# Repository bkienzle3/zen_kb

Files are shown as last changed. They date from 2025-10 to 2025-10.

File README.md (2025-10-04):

# zen_kb

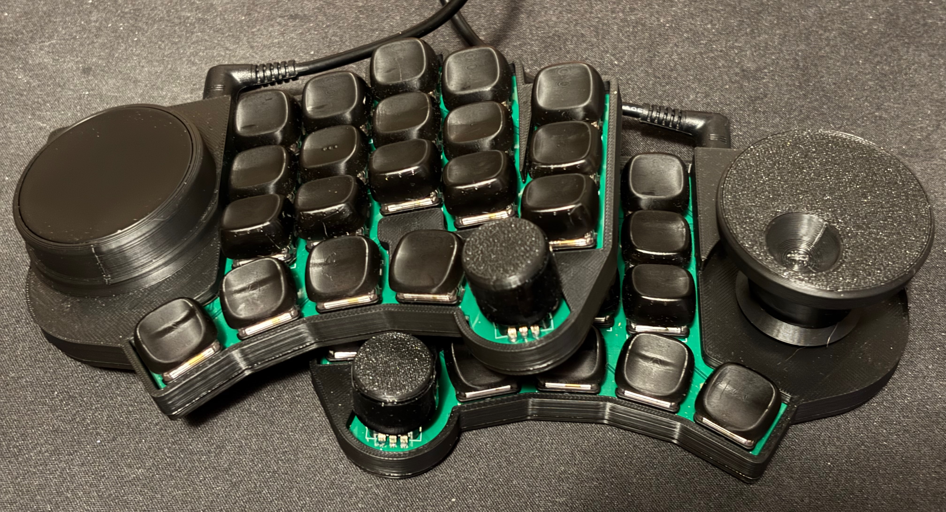
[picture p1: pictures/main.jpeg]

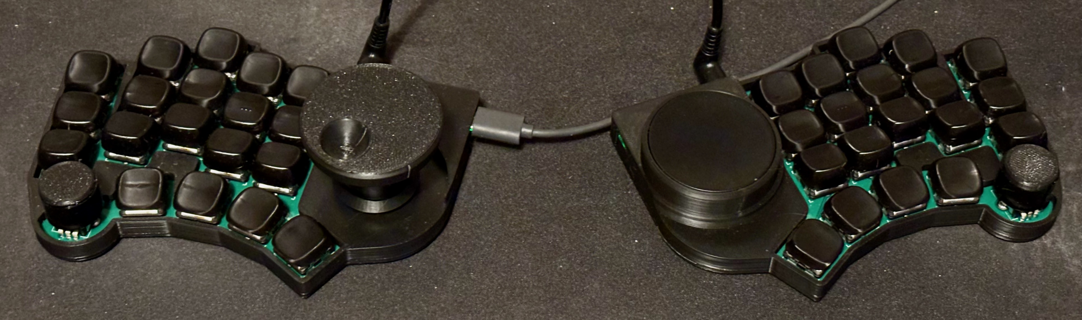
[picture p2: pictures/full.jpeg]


"Maximalist" ergo mech split keyboard. 38-keys, 3 rotary encoders, 1 trackpad. My last keyboard was mu (無), meaning nothing. Since this adds a lot of extra bells and whistles, I've named it zen (全), meaning all. This keyboard is meant to be much more "finished" than mu. With that said, this is still an eternal work in progress. The hardware is finished, at least. The config is a never ending journey.

## Firmware
Firmware is located in qmk_firmware. Keymaps are based on Miryoku (manna-harbour/miryoku), with my own customizations, of course.

## Bill of materials

Kailh Choc V1 key switches x 38
<br>KB2040 x 2 (MCU - runs on 3.3v, important for trackpad)
<br>1N4148 MiniMELF diode x 38
<br>TRRS-PJ-320A x 2 (TRRS jacks)
<br>Alps EC12E2440301 x 2 (Mini encoders)
<br>Alps EC12E24404A8 x 1 (Jog wheel encoder)
<br>Cirque TM040040-2024-303 x 1 (trackpad)
<br>Molex 505110-1297 x 1
<br>.50 mm pitch type B FFC x 1
<br>M2*6mm screws, hex socket head x 12
<br>M2 heat set inserts x 12

## Other
I recommend putting some sort of grip tape around the knobs. I'm using self-fusing silicone tape, but anything should work.

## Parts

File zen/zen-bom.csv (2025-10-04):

Id | Designator | Footprint | Quantity | Designation | Supplier and ref
1 | ,,,,,,,,,, |  | 11
2 | SW22,SW23,SW18,SW26,SW38,SW33,SW11,SW19,SW30,SW37,SW17,SW5,SW24,SW2,SW7,SW6,SW32,SW13,SW27,SW4,SW12,SW16,SW34,SW1,SW3,SW14,SW29,SW25,SW31,SW28,SW21,SW9,SW36,SW35,SW20,SW15,SW10,SW8 | SW_PG1350 | 38 | SW_Push
3 | U1,U2 | kb2040 | 2 | kb2040
4 | TRX2,TRX1 | TRRS-PJ-320A | 2 | TRRS
5 | ENC2,JOG1,ENC1 | EC12E2440301 | 3 | RotaryEncoder
6 | REF1,REF1 | Cirque Curved 40mm Trackpad | 2 | Cirque Curved Trackpad
7 | TKP1 | 5051101297 | 1 | Trackpad
8 | D33,D15,D14,D6,D38,D2,D31,D9,D22,D13,D26,D17,D24,D12,D36,D1,D16,D11,D28,D29,D7,D35,D8,D10,D20,D37,D23,D21,D32,D18,D3,D19,D25,D5,D27,D30,D4,D34 | D_MiniMELF | 38 | D

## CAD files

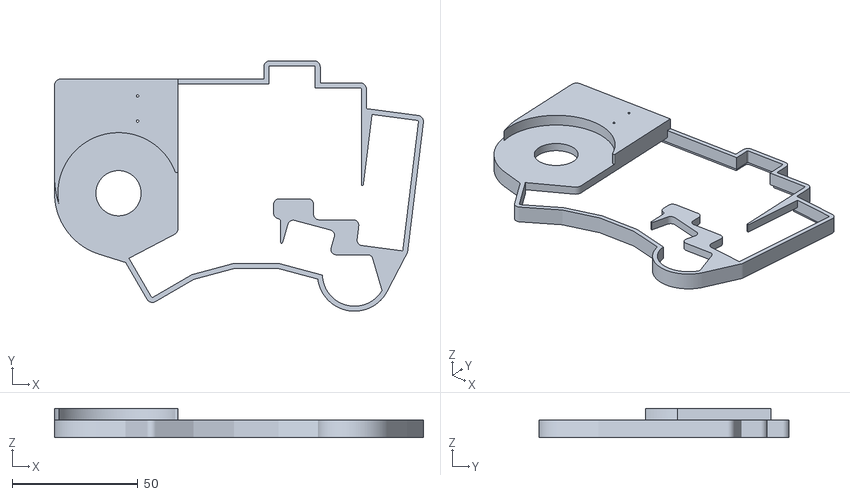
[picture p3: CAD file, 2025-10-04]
3d-printed-parts/case/topleft-needsmirrored.stl
147.0 x 99.7 x 11.6

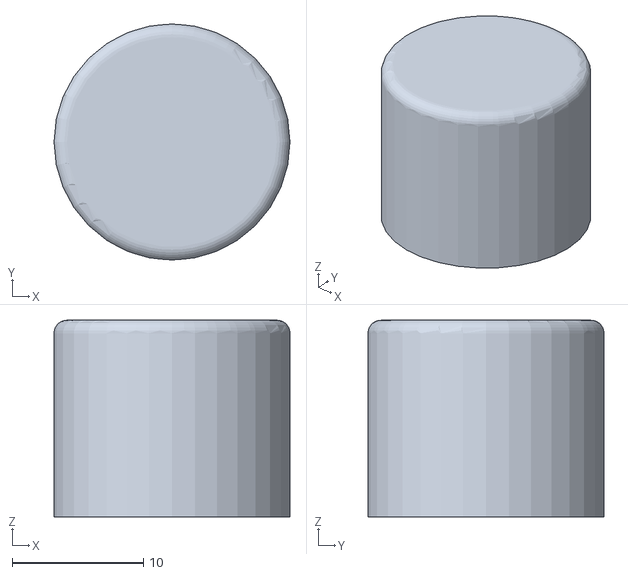
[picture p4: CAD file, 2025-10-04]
3d-printed-parts/wheels/smallknobs.stl
18.0 x 18.0 x 15.0

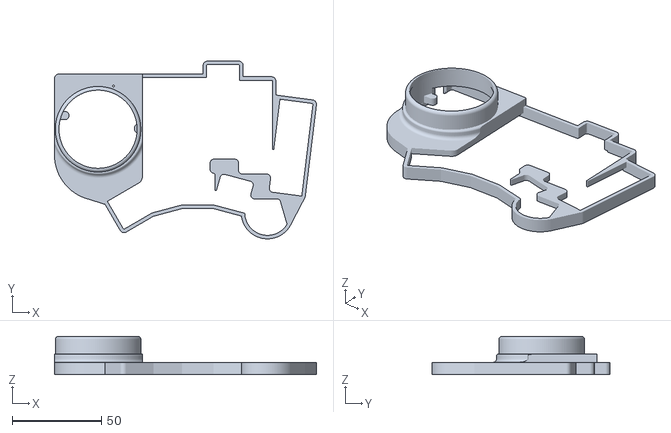
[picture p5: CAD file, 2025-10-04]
3d-printed-parts/case/topright.stl
147.0 x 99.7 x 21.6

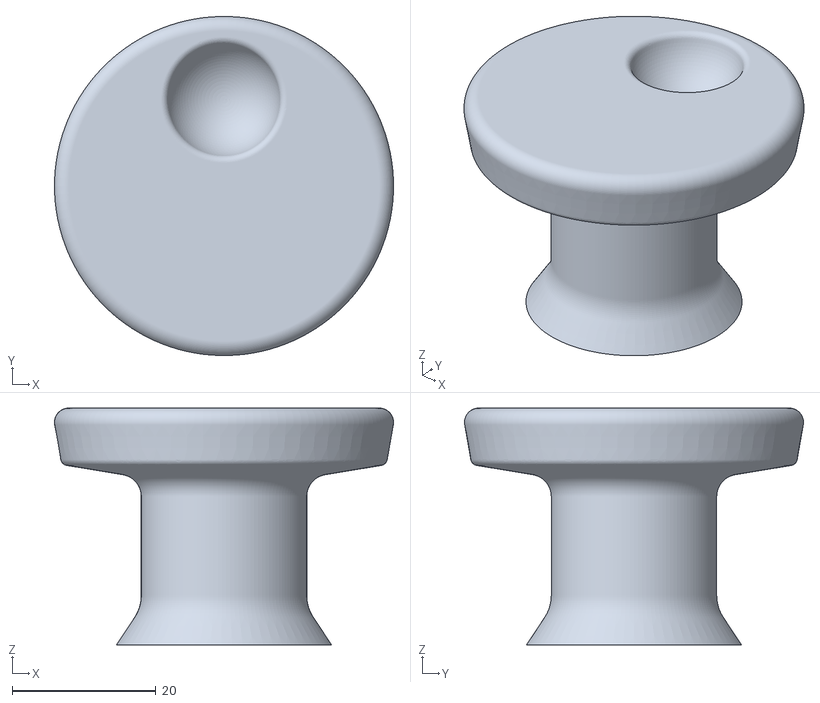
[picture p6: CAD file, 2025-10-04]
3d-printed-parts/wheels/jogwheel.stl
47.2 x 47.2 x 33.0

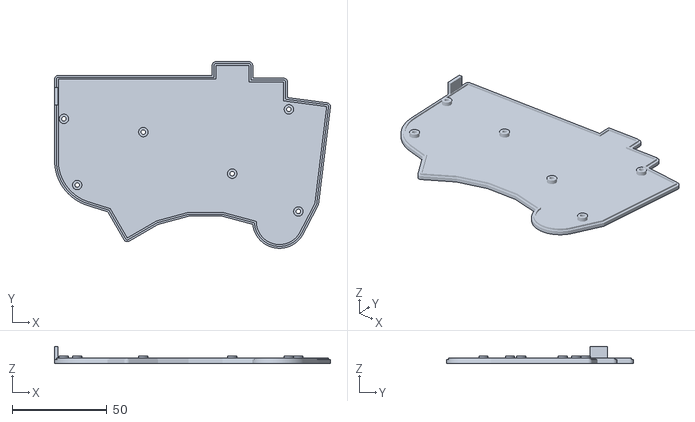
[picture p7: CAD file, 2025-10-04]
3d-printed-parts/case/bottom.stl
146.0 x 98.7 x 9.00

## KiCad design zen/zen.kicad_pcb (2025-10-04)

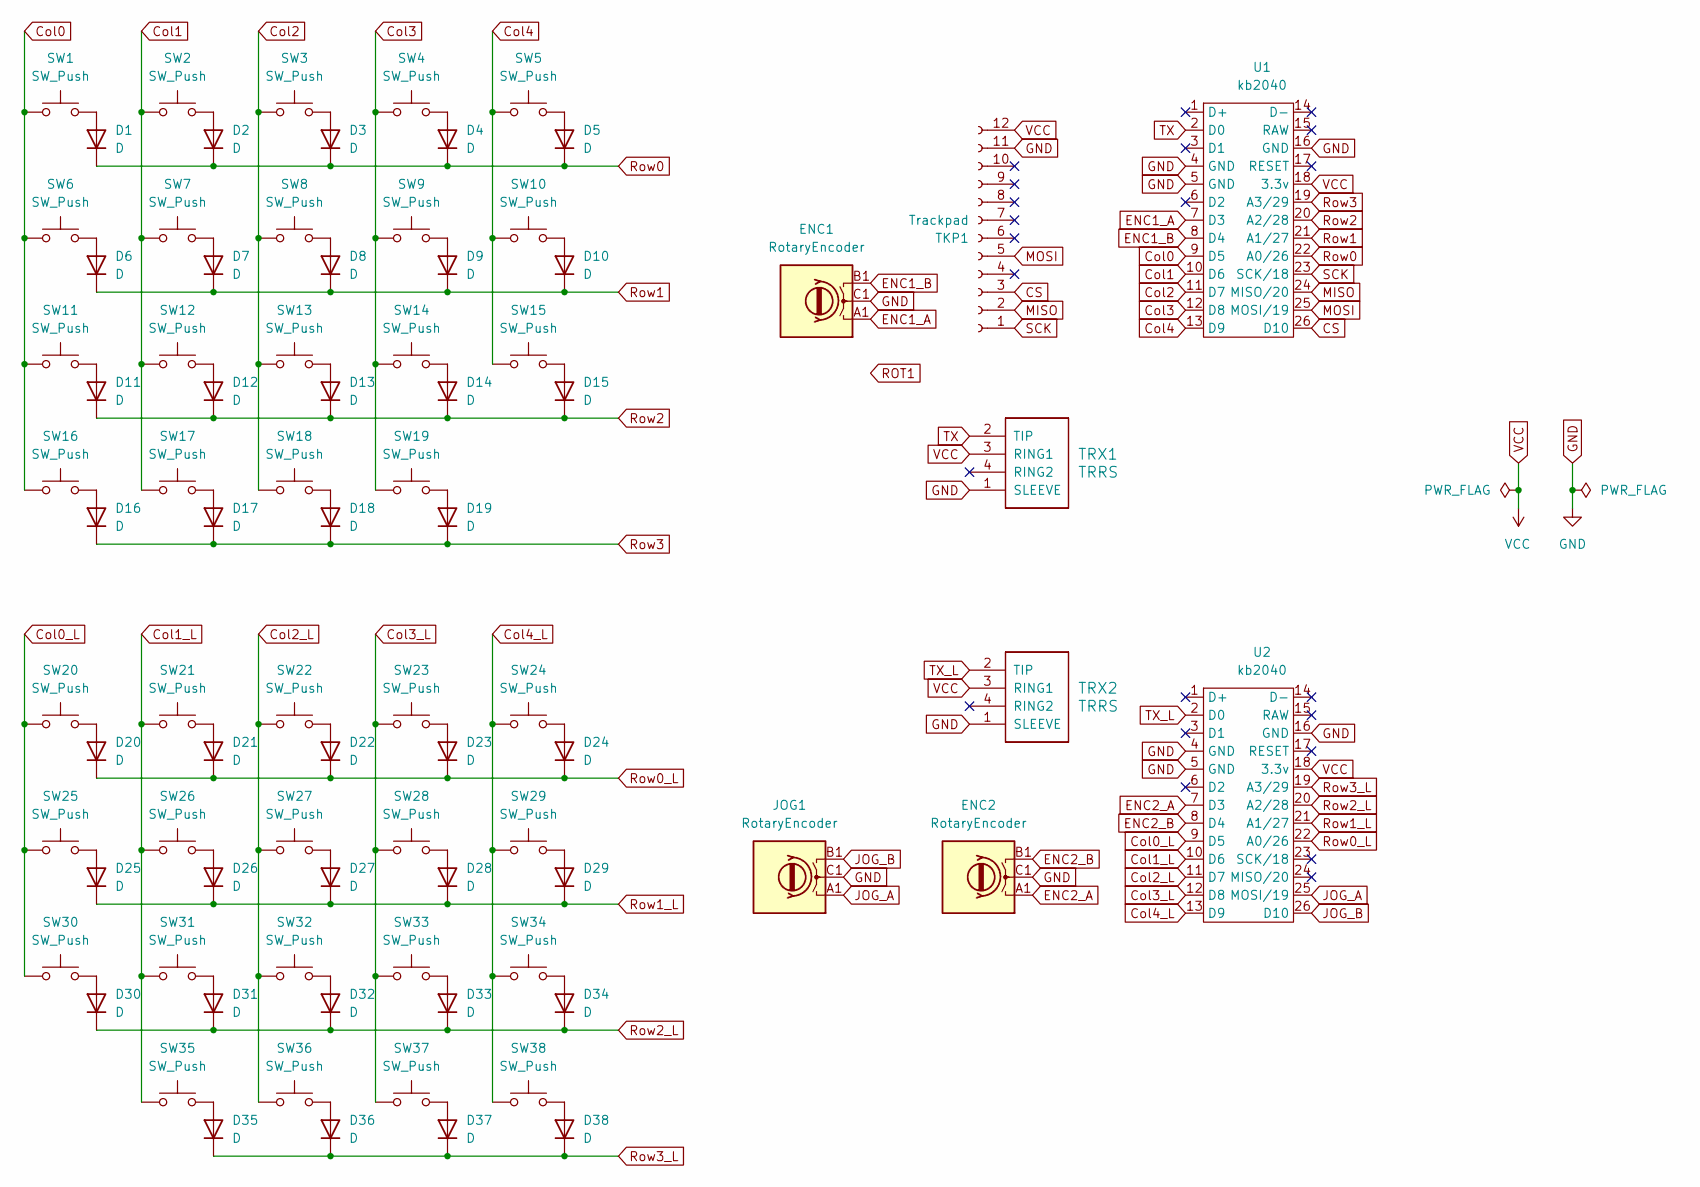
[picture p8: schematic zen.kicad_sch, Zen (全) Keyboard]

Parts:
D1, D2, D3, D4, D5, D6, D7, D8, D9, D10, D11, D12, D13, D14, D15, D16, D17, D18, D19, D20, D21, D22, D23, D24, D25, D26, D27, D28, D29, D30, D31, D32, D33, D34, D35, D36, D37, D38: D; D_MiniMELF
ENC1, ENC2: RotaryEncoder; EC12E2440301
JOG1: RotaryEncoder; EC12E2440301
SW1, SW2, SW3, SW4, SW5, SW6, SW7, SW8, SW9, SW10, SW11, SW12, SW13, SW14, SW15, SW16, SW17, SW18, SW19, SW20, SW21, SW22, SW23, SW24, SW25, SW26, SW27, SW28, SW29, SW30, SW31, SW32, SW33, SW34, SW35, SW36, SW37, SW38: SW_Push; SW_PG1350
TKP1: Trackpad; 5051101297
TRX1, TRX2: TRRS; TRRS-PJ-320A
U1, U2: kb2040

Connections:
CS: TKP1.3, U1.26 (D10)
Col0: SW1.1, SW6.1, SW11.1, SW16.1, U1.9 (D5)
Col0_L: SW20.1, SW25.1, SW30.1, U2.9 (D5)
Col1: SW2.1, SW7.1, SW12.1, SW17.1, U1.10 (D6)
Col1_L: SW21.1, SW26.1, SW31.1, SW35.1, U2.10 (D6)
Col2: SW3.1, SW8.1, SW13.1, SW18.1, U1.11 (D7)
Col2_L: SW22.1, SW27.1, SW32.1, SW36.1, U2.11 (D7)
Col3: SW4.1, SW9.1, SW14.1, SW19.1, U1.12 (D8)
Col3_L: SW23.1, SW28.1, SW33.1, SW37.1, U2.12 (D8)
Col4: SW5.1, SW10.1, SW15.1, U1.13 (D9)
Col4_L: SW24.1, SW29.1, SW34.1, SW38.1, U2.13 (D9)
ENC1_A: ENC1.A1, U1.7 (D3)
ENC1_B: ENC1.B1, U1.8 (D4)
ENC2_A: ENC2.A1, U2.7 (D3)
ENC2_B: ENC2.B1, U2.8 (D4)
GND: ENC1.C1, ENC2.C1, JOG1.C1, TKP1.11, TRX1.1 (SLEEVE), TRX2.1 (SLEEVE), U1.4 (GND), U1.5 (GND), U1.16 (GND), U2.4 (GND), U2.5 (GND), U2.16 (GND)
JOG_A: JOG1.A1, U2.25 (MOSI/19)
JOG_B: JOG1.B1, U2.26 (D10)
MISO: TKP1.2, U1.24 (MISO/20)
MOSI: TKP1.5, U1.25 (MOSI/19)
unnamed: D1.2 (A), SW1.2
unnamed: D2.2 (A), SW2.2
unnamed: D3.2 (A), SW3.2
unnamed: D4.2 (A), SW4.2
unnamed: D5.2 (A), SW5.2
unnamed: D6.2 (A), SW6.2
unnamed: D7.2 (A), SW7.2
unnamed: D8.2 (A), SW8.2
unnamed: D9.2 (A), SW9.2
unnamed: D10.2 (A), SW10.2
unnamed: D11.2 (A), SW11.2
unnamed: D12.2 (A), SW12.2
unnamed: D13.2 (A), SW13.2
unnamed: D14.2 (A), SW14.2
unnamed: D15.2 (A), SW15.2
unnamed: D16.2 (A), SW16.2
unnamed: D17.2 (A), SW17.2
unnamed: D18.2 (A), SW18.2
unnamed: D19.2 (A), SW19.2
unnamed: D20.2 (A), SW20.2
unnamed: D21.2 (A), SW21.2
unnamed: D22.2 (A), SW22.2
unnamed: D23.2 (A), SW23.2
unnamed: D24.2 (A), SW24.2
unnamed: D25.2 (A), SW25.2
unnamed: D26.2 (A), SW26.2
unnamed: D27.2 (A), SW27.2
unnamed: D28.2 (A), SW28.2
unnamed: D29.2 (A), SW29.2
unnamed: D30.2 (A), SW30.2
unnamed: D31.2 (A), SW31.2
unnamed: D32.2 (A), SW32.2
unnamed: D33.2 (A), SW33.2
unnamed: D34.2 (A), SW34.2
unnamed: D35.2 (A), SW35.2
unnamed: D36.2 (A), SW36.2
unnamed: D37.2 (A), SW37.2
unnamed: D38.2 (A), SW38.2
Row0: D1.1 (K), D2.1 (K), D3.1 (K), D4.1 (K), D5.1 (K), U1.22 (A0/26)
Row0_L: D20.1 (K), D21.1 (K), D22.1 (K), D23.1 (K), D24.1 (K), U2.22 (A0/26)
Row1: D6.1 (K), D7.1 (K), D8.1 (K), D9.1 (K), D10.1 (K), U1.21 (A1/27)
Row1_L: D25.1 (K), D26.1 (K), D27.1 (K), D28.1 (K), D29.1 (K), U2.21 (A1/27)
Row2: D11.1 (K), D12.1 (K), D13.1 (K), D14.1 (K), D15.1 (K), U1.20 (A2/28)
Row2_L: D30.1 (K), D31.1 (K), D32.1 (K), D33.1 (K), D34.1 (K), U2.20 (A2/28)
Row3: D16.1 (K), D17.1 (K), D18.1 (K), D19.1 (K), U1.19 (A3/29)
Row3_L: D35.1 (K), D36.1 (K), D37.1 (K), D38.1 (K), U2.19 (A3/29)
SCK: TKP1.1, U1.23 (SCK/18)
TX: TRX1.2 (TIP), U1.2 (D0)
TX_L: TRX2.2 (TIP), U2.2 (D0)
VCC: TKP1.12, TRX1.3 (RING1), TRX2.3 (RING1), U1.18 (3.3v), U2.18 (3.3v)

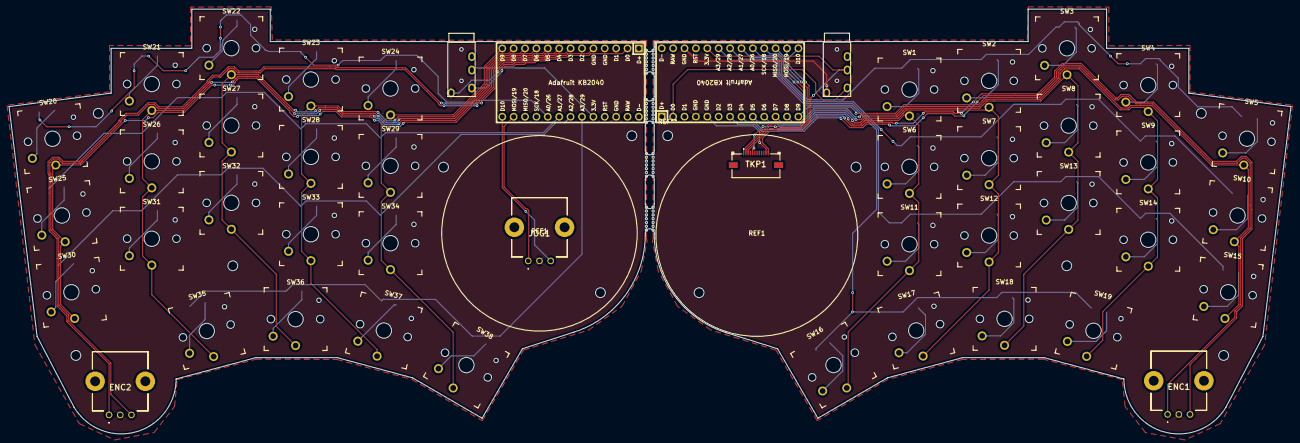
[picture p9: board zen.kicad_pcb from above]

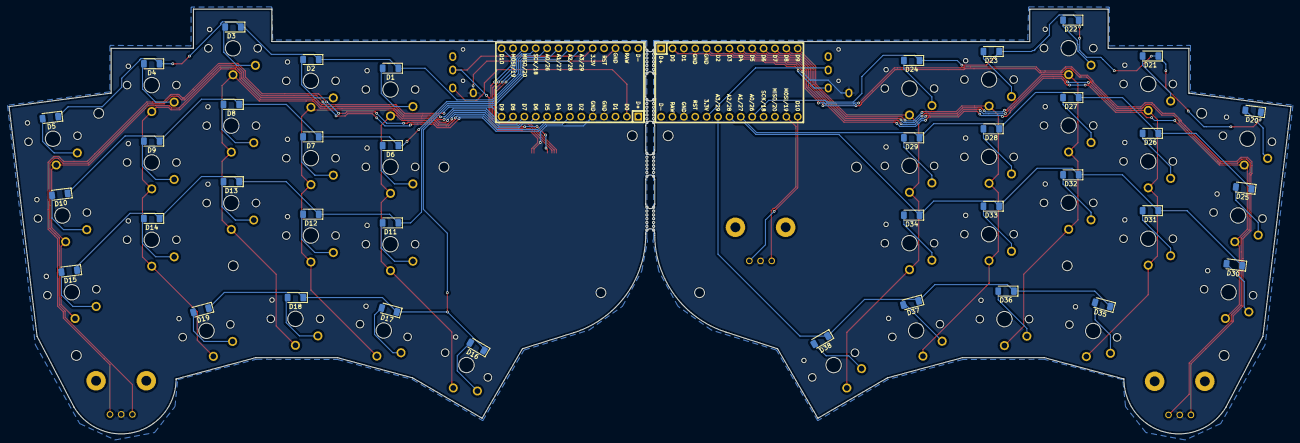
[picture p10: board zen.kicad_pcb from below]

Board: 2 copper layers, 285.9 x 94.7 mm, 86 parts (38 on the bottom side), 70 nets.

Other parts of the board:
REF1, REF1#2: Cirque Curved Trackpad; Cirque Curved 40mm Trackpad

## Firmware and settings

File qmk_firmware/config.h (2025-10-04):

// Copyright 2025 bkienzle3 (@bkienzle3)
// SPDX-License-Identifier: GPL-2.0-or-later

#pragma once

/*
 * Feature disable options
 *  These options are also useful to firmware size reduction.
 */

/* disable debug print */
//#define NO_DEBUG

#define ENCODER_A_PINS { GP3, GP19 }
#define ENCODER_B_PINS { GP4, GP10 }
#define ENCODER_RESOLUTIONS { 4, 4 }
#define ENCODER_A_PINS_RIGHT { GP3 }
#define ENCODER_B_PINS_RIGHT { GP4 }
#define ENCODER_RESOLUTIONS_RIGHT { 4 }



#define SPLIT_POINTING_ENABLE
#define POINTING_DEVICE_RIGHT
#define CIRQUE_PINNACLE_TAP_ENABLE
#define CIRQUE_PINNACLE_SECONDARY_TAP_ENABLE
#define POINTING_DEVICE_ROTATION_90
#define CIRQUE_PINNACLE_ATTENUATION EXTREG__TRACK_ADCCONFIG__ADC_ATTENUATE_2X
#define CIRQUE_PINNACLE_CURVED_OVERLAY

//#define SPI_DRIVER SPID0
#define SPI_SCK_PIN GP18
#define SPI_MOSI_PIN GP19
#define SPI_MISO_PIN GP20
#define POINTING_DEVICE_CS_PIN GP10
#undef CIRQUE_PINNACLE_DIAMETER_MM
#define CIRQUE_PINNACLE_DIAMETER_MM 40

//#define SPI_MOSI_PIN GP19
//#define SPI_MOSI_PIN GP20
/* disable print */
//#define NO_PRINT

/* disable action features */
//#define NO_ACTION_LAYER
//#define NO_ACTION_TAPPING
#define NO_ACTION_ONESHOT

// handedness
#define EE_HANDS

// mouse settings
#define MOUSEKEY_INTERVAL 16
#define MOUSEKEY_TIME_TO_MAX 60
#define MOUSEKEY_MAX_SPEED 15
#define MOUSEKEY_MOVE_DELTA 3
#define MOUSEKEY_DELAY 10
#define MOUSEKEY_WHEEL_DELTA 1
#define MOUSEKEY_WHEEL_MAX_SPEED 1

// homerow mods
#define TAPPING_TERM 200
#define QUICK_TAP_TERM 90
#define TAPPING_TERM_PER_KEY

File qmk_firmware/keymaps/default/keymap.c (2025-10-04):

#include QMK_KEYBOARD_H


/* zen keymap
 * home row mods
 */


// layers
enum layers {
    BASE = 0,
    NAV,
    SYM,
    MOUSE,
    NUMS,
    FNS,
    MEDIA,
    CFG,
    BUTTON,
    GFPS,
    GGEN,
    GEXT,
};


//// home row mods for qwerty
#define KC_HRA LGUI_T(KC_A)
#define KC_HRS LALT_T(KC_S)
#define KC_HRD LSFT_T(KC_D)
#define KC_HRF LCTL_T(KC_F)
#define KC_HRJ LCTL_T(KC_J)
#define KC_HRK LSFT_T(KC_K)
#define KC_HRL LALT_T(KC_L)
#define KC_HRQU LGUI_T(KC_QUOT)

// button layer tap
#define KC_BLTZ LT(BUTTON, KC_Z)
#define KC_BLTSH LT(BUTTON, KC_SLSH)

//// thumb buttons
#define KC_THT LT(NAV,KC_TAB)
#define KC_THS LT(MOUSE,KC_SPC)
#define KC_THE LT(SYM,KC_ENT)
#define KC_THB LT(NUMS,KC_BSPC)
#define KC_THESC LT(MEDIA,KC_ESC)
#define KC_THDEL LT(FNS,KC_DEL)

//// copy/paste
#define KC_MCOPY LCTL(KC_C)
#define KC_MPSTE LCTL(KC_V)
#define KC_MCUT LCTL(KC_X)
#define KC_MUNDO LCTL(KC_Z)
#define KC_MREDO LCTL(KC_Y)

//// misc
#define KC_PRVL LALT(KC_LEFT)
#define KC_MSBCK MS_BTN4
#define KC_MSFWD MS_BTN5
#define BR_NTAB LCTL(KC_PGDN)
#define BR_PTAB LCTL(KC_PGUP)

/// gaming
#define KC_GEXT MO(GEXT)
#define KC_GFPS TG(GFPS)
#define KC_GGEN TG(GGEN)
#define KC_BASE TG(BASE)
#define KC_ENTGX LT(GEXT,KC_ENT)


const uint16_t PROGMEM keymaps[][MATRIX_ROWS][MATRIX_COLS] = {



   // base (qwerty) layer
   [BASE] = LAYOUT_split_3x5_4(
   //,--------------------------------------------.                    ,--------------------------------------------.
          KC_Q,    KC_W,    KC_E,    KC_R,    KC_T,                         KC_Y,    KC_U,    KC_I,    KC_O,    KC_P,
   //|--------+--------+--------+--------+--------|                    |--------+--------+--------+--------+--------|
        KC_HRA,  KC_HRS,  KC_HRD,  KC_HRF,    KC_G,                         KC_H,  KC_HRJ,  KC_HRK,  KC_HRL, KC_HRQU,
   //|--------+--------+--------+--------+--------|                    |--------+--------+--------+--------+--------|
       KC_BLTZ,    KC_X,    KC_C,    KC_V,    KC_B,                         KC_N,    KC_M, KC_COMM,  KC_DOT,KC_BLTSH,
   //|--------+--------+--------+--------+--------+--------|  |--------+--------+--------+--------+--------+--------|
                           KC_NO,KC_THESC,  KC_THT,  KC_THS,     KC_THE,  KC_THB, KC_THDEL,  KC_NO
                     //`-----------------------------------'  `-----------------------------------'
   ),

   // nav layer
   [NAV] = LAYOUT_split_3x5_4(
   //,--------------------------------------------.                    ,--------------------------------------------.
        KC_F13,  KC_F14,  KC_F15,  KC_F16,  KC_F17,                     KC_MPSTE,KC_MCOPY, KC_MCUT,KC_MUNDO,KC_MREDO,
   //|--------+--------+--------+--------+--------|                    |--------+--------+--------+--------+--------|
       KC_LGUI, KC_LALT, KC_LSFT, KC_LCTL, KC_PRVL,                      KC_LEFT, KC_DOWN,   KC_UP, KC_RGHT, KC_CAPS,
   //|--------+--------+--------+--------+--------|                    |--------+--------+--------+--------+--------|
        KC_APP,  KC_F18,  KC_F19,  KC_F21,  KC_F22,                      KC_HOME, KC_PGDN, KC_PGUP,  KC_END,  KC_INS,
   //|--------+--------+--------+--------+--------+--------|  |--------+--------+--------+--------+--------+--------|
                           KC_NO, KC_TRNS, KC_TRNS, KC_TRNS,     KC_ENT, KC_BSPC,  KC_DEL,   KC_NO
                     //`-----------------------------------'  `-----------------------------------'
   ),

   // mouse/fancy/orphans
   [MOUSE] = LAYOUT_split_3x5_4(
   //,--------------------------------------------.                    ,--------------------------------------------.
         KC_NO,   KC_NO,   KC_NO,   KC_NO,   KC_NO,                     KC_MSBCK,   KC_NO,   KC_NO,KC_MSFWD,   KC_NO,
   //|--------+--------+--------+--------+--------|                    |--------+--------+--------+--------+--------|
       KC_LGUI, KC_LALT, KC_LSFT, KC_LCTL,   KC_NO,                      MS_LEFT, MS_DOWN,   MS_UP, MS_RGHT,   KC_NO,
   //|--------+--------+--------+--------+--------|                    |--------+--------+--------+--------+--------|
         KC_NO,   KC_NO,   KC_NO,   KC_NO,   KC_NO,                      MS_WHLL, MS_WHLD, MS_WHLU, MS_WHLR,   KC_NO,
   //|--------+--------+--------+--------+--------+--------|  |--------+--------+--------+--------+--------+--------|
                           KC_NO, KC_TRNS, KC_TRNS, KC_TRNS,    MS_BTN1, MS_BTN2, MS_BTN3,   KC_NO
                     //`-----------------------------------'  `-----------------------------------'
   ),

   // convienience buttons
   [BUTTON] = LAYOUT_split_3x5_4(
   //,--------------------------------------------.                    ,--------------------------------------------.
         KC_NO,  KC_F10,  KC_F11,  KC_F12,  KC_F24,                        KC_NO,   KC_NO,   KC_NO, KC_WAKE,  KC_PWR,
   //|--------+--------+--------+--------+--------|                    |--------+--------+--------+--------+--------|
         KC_NO,   KC_NO,   KC_NO,   KC_F5,KC_MUNDO,                        KC_NO,   KC_NO,   KC_NO,   KC_NO,   KC_NO,
   //|--------+--------+--------+--------+--------|                    |--------+--------+--------+--------+--------|
         KC_NO, KC_MCUT,KC_MCOPY,KC_MPSTE,KC_MREDO,                      MS_WHLL, MS_WHLD, MS_WHLU, MS_WHLR,   KC_NO,
   //|--------+--------+--------+--------+--------+--------|  |--------+--------+--------+--------+--------+--------|
                           KC_NO,   KC_NO,   KC_NO,   KC_NO,      KC_NO,   KC_NO,   KC_NO,   KC_NO
                     //`-----------------------------------'  `-----------------------------------'
   ),

   // numbers
   [NUMS] = LAYOUT_split_3x5_4(
   //,--------------------------------------------.                    ,--------------------------------------------.
       KC_LBRC,    KC_7,    KC_8,    KC_9, KC_RBRC,                        KC_NO,    KC_A,    KC_B,    KC_C,   KC_NO,
   //|--------+--------+--------+--------+--------|                    |--------+--------+--------+--------+--------|
       KC_SCLN,    KC_4,    KC_5,    KC_6,  KC_EQL,                      KC_GFPS, KC_LCTL, KC_LSFT, KC_LALT, KC_LGUI,
   //|--------+--------+--------+--------+--------|                    |--------+--------+--------+--------+--------|
        KC_GRV,    KC_1,    KC_2,    KC_3, KC_BSLS,                      KC_GGEN,    KC_D,    KC_E,    KC_F,   KC_NO,
   //|--------+--------+--------+--------+--------+--------|  |--------+--------+--------+--------+--------+--------|
                           KC_NO,  KC_DOT,  KC_MINS,   KC_0,    KC_TRNS, KC_TRNS, KC_TRNS,   KC_NO
                     //`-----------------------------------'  `-----------------------------------'
   ),
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

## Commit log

2025-09-01 initial commit, pcb design well underway
    [zen.kicad_pcb, zen.kicad_sch]
2025-10-04 pcb complete
    [zen-B_Cu.gbl, zen-B_Mask.gbs, zen-B_Paste.gbp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]
2025-10-04 add 3d printed parts
    [bottom.stl, jogwheel.stl, smallknobs.stl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]
